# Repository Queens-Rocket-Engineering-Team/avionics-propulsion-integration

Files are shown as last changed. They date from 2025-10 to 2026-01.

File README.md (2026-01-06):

# Propulsion Integration Control Boards (Upper, Lower)
> 2025-2026 Season - Propulsion Integration Projects

-  Branch contains both board's **firmware**, **schematics**, and related **documentation and datasheets**.

### Folder Structure
- [`/Schematics`](./Schematics/) : PCB design files (KiCad V8)  
- [`/Firmware`](./Firmware/) : Arduino C/C++ code (to ESP32) for sensors, CAN/TWAI, and WiFi telemetry  
- [`/Datasheets`](./Datasheets/) : Datasheets and reference materials  
- [`.gitignore`](./.gitignore) : Build and temporary files excluded

---

**Branch created by:** Jeevan Sanchez

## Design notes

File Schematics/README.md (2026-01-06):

# LC Board Schematics

This directory contains PCB and schematic files for both LC boards (Kicad v8.0.6). 

Including:

- power managment for the ESP32 and board.
- MCU breakout circuitry, valve control, sensing circuits, communication.
- board layout and component placement.

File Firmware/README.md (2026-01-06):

# LC Board Firmware

This directory contains the ESP32 firmware for the launch control (LC) board. 

Including:

- reading sensors. 
- valve control.
- CAN protocol communication.

 Firmware is developed in Arduino C/C++ and will be flashed via USB.

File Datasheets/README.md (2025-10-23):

# LC Board Datasheets

This directory contains datasheets, reference documents, and technical notes for LC board components, including:

- ESP32 MCU
- any interfaced hardware (sensors, CAN transceiver, etc.)
- software docs (external libs, etc.)

- more documentation/notes/research can be found on the <a href="https://www.notion.so/native/qret-ohyeah/Propulsion-Integration-Projects-261401792b9b805eae9ad54960dac8c4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">Notion<a/>

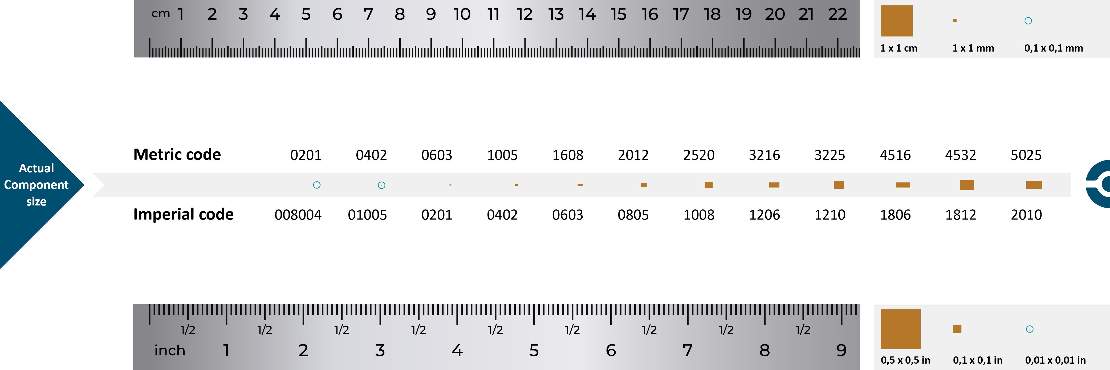
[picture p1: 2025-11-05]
Datasheets/SMD_SIZECHART.jpg

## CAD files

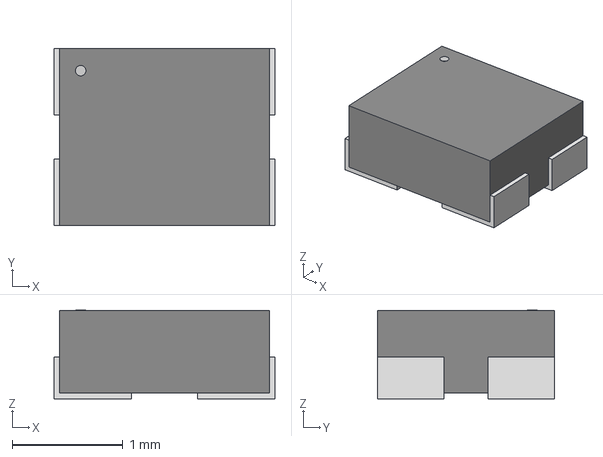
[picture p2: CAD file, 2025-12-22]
Schematics/upper_lc_board/models/SON4_SIT1602-7_SIT.step
2.00 x 1.60 x 0.803 mm

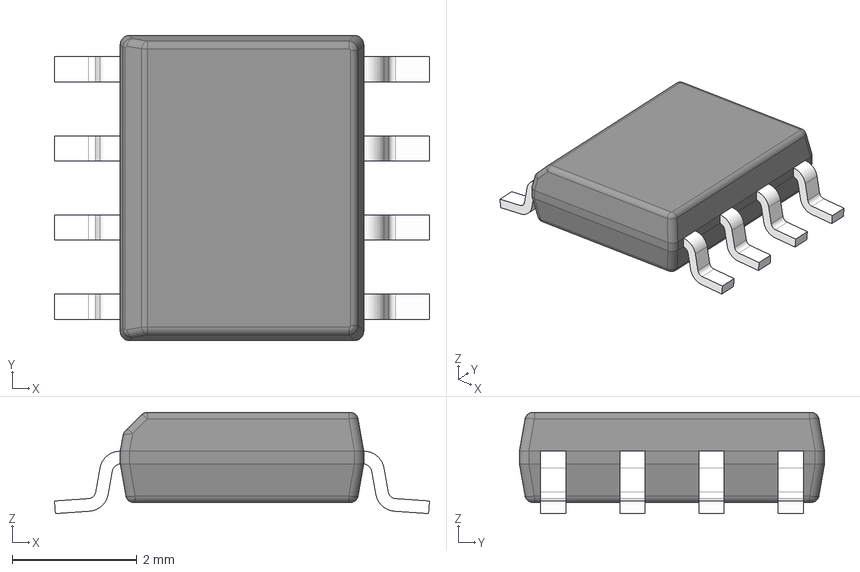
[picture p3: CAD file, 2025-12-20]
Schematics/upper_lc_board/models/D0008A.stp
6.02 x 4.90 x 1.63 mm
BODY-SO
LEAD-D0008A x 8

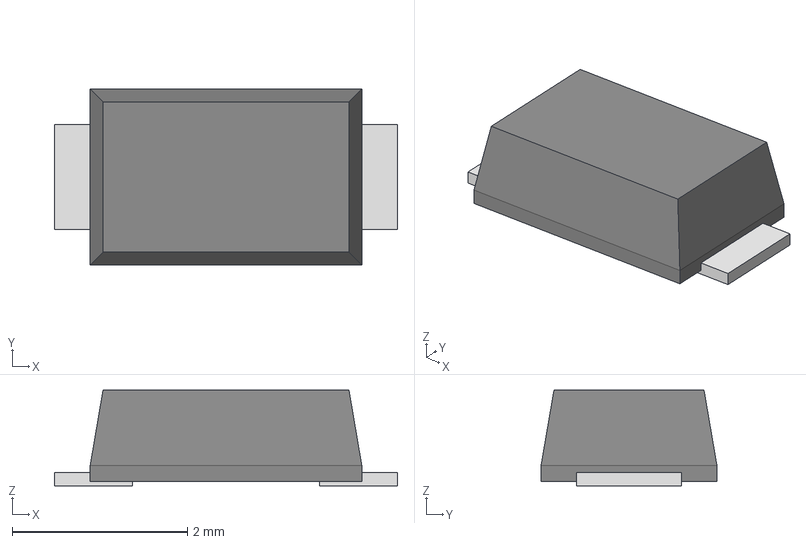
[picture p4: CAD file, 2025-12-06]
Schematics/upper_lc_board/models/SOD-123F_LTF.step
3.91 x 2.01 x 1.09 mm

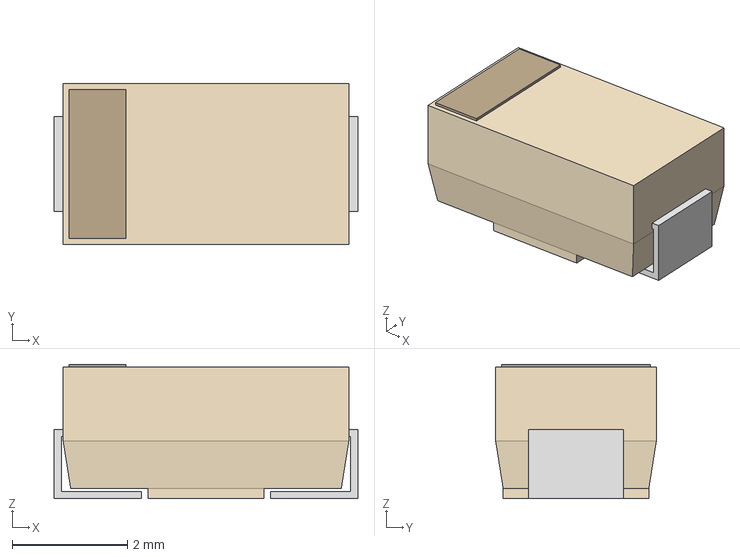
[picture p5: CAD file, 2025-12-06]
Schematics/upper_lc_board/models/SMASeries_LTF.step
5.28 x 2.79 x 2.34 mm

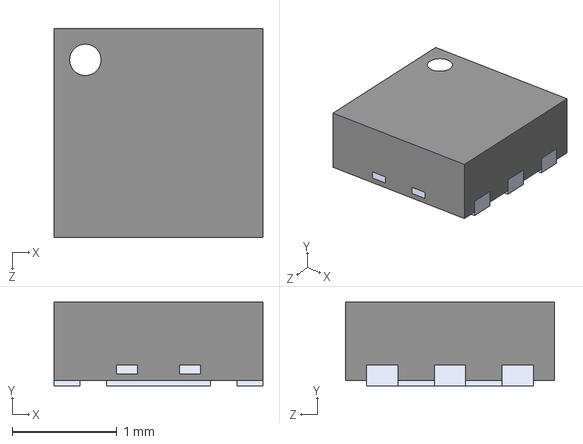
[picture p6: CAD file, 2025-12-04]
Schematics/upper_lc_board/models/TMP117MAIDRVR.step
2.00 x 0.8 x 2.00 mm

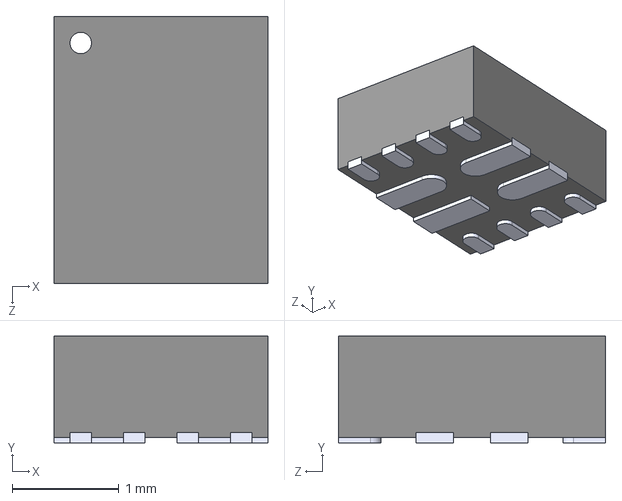
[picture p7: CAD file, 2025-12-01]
Schematics/upper_lc_board/models/TPS2121RUXR.step
2.00 x 1.00 x 2.50 mm

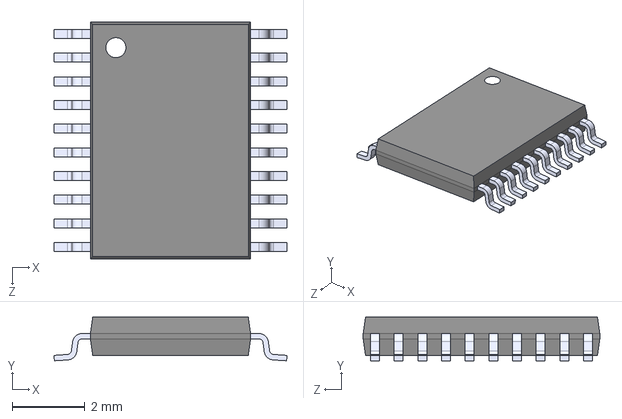
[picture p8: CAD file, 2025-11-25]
Schematics/upper_lc_board/models/ADS131M04IPWR.step
6.40 x 1.20 x 6.50 mm

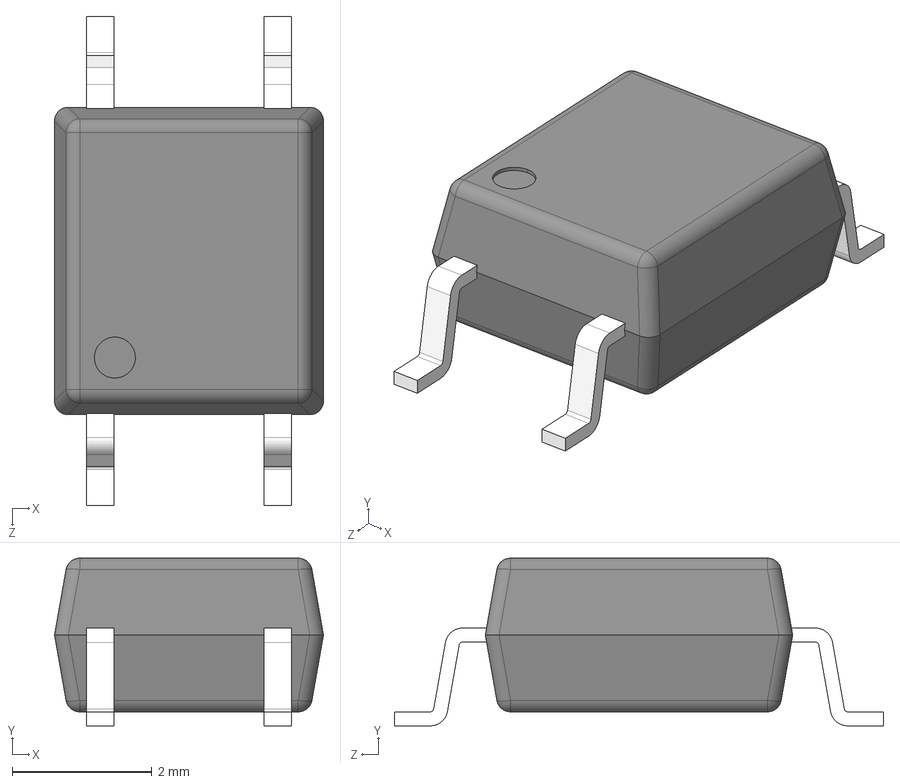
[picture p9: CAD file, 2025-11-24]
Schematics/upper_lc_board/models/VO1400AEFT1.STEP
3.85 x 2.40 x 7.00 mm

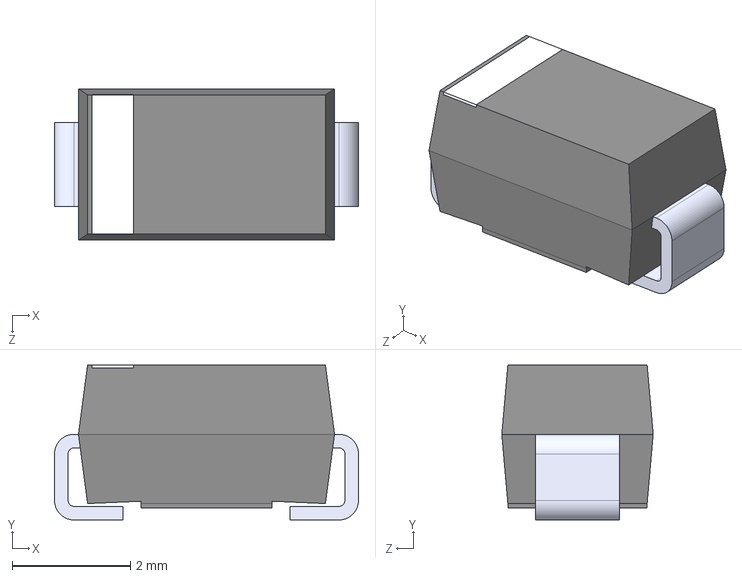
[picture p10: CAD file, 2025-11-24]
Schematics/upper_lc_board/models/US1M.step
5.14 x 2.62 x 2.56 mm

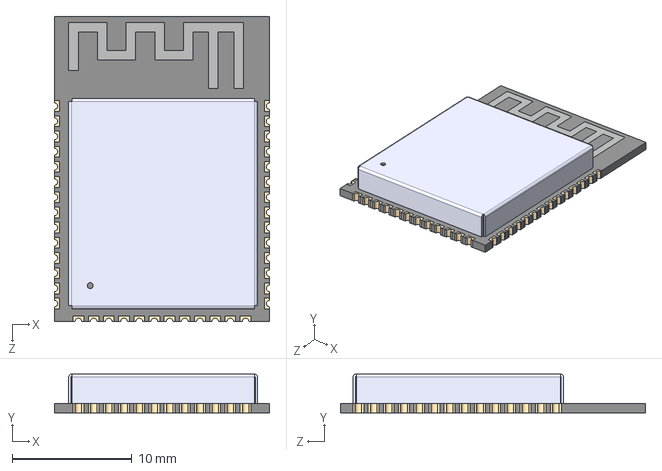
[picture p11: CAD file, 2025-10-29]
Schematics/upper_lc_board/models/ESP32-S3-WROOM-1-N16R2.step
18.0 x 3.25 x 25.5 mm

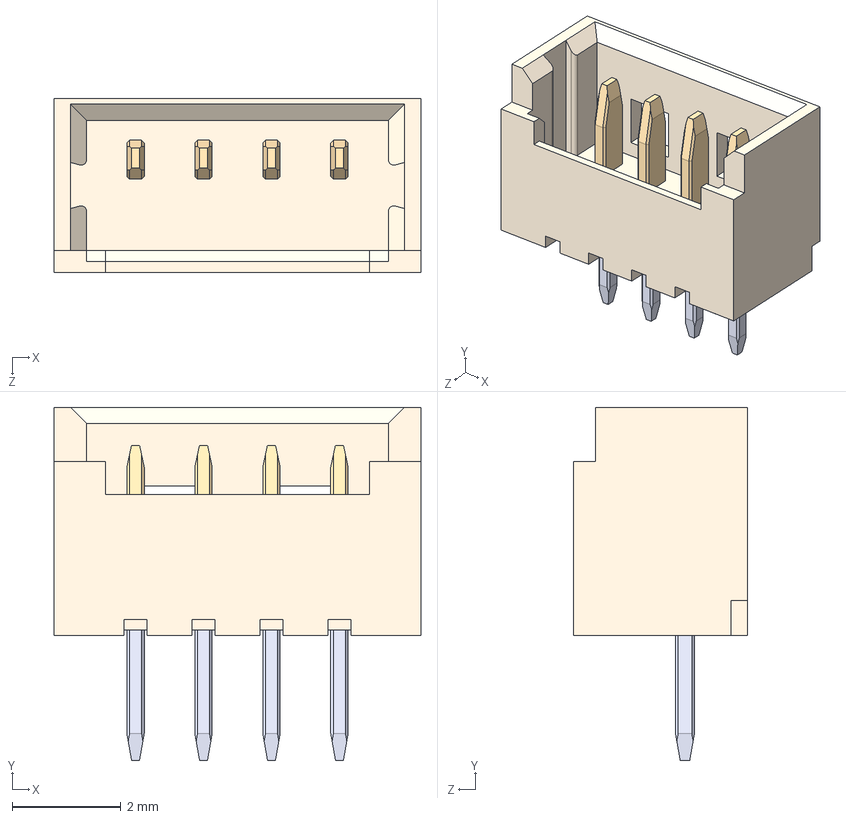
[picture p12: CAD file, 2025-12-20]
Schematics/upper_lc_board/models/53047-0460.step
6.75 x 6.50 x 3.20 mm

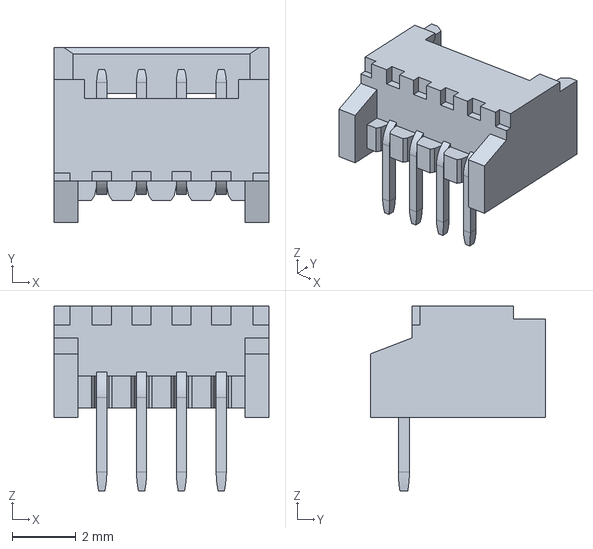
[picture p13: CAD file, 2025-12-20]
Schematics/upper_lc_board/models/530480410.step
6.75 x 5.50 x 5.80 mm

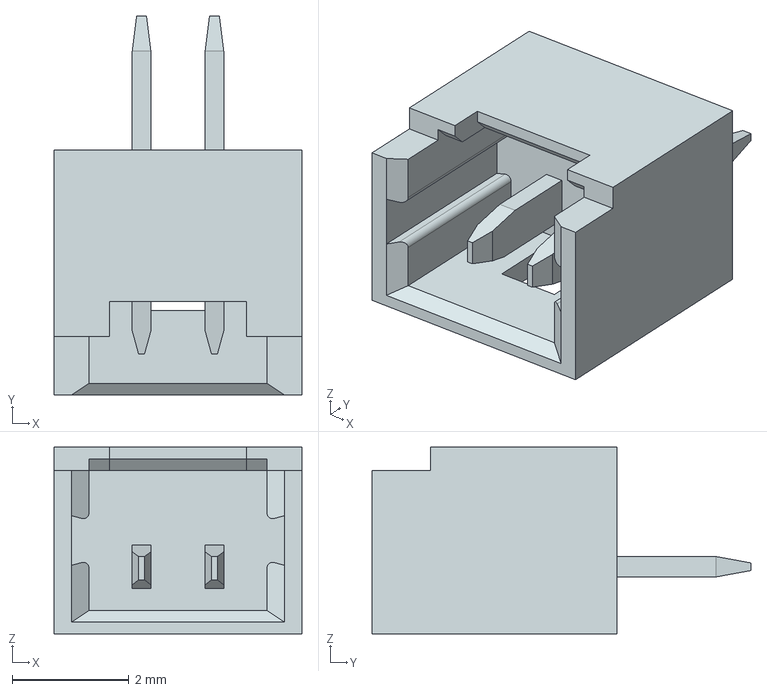
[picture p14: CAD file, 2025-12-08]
Schematics/upper_lc_board/models/530470260.stp
4.25 x 6.50 x 3.20 mm

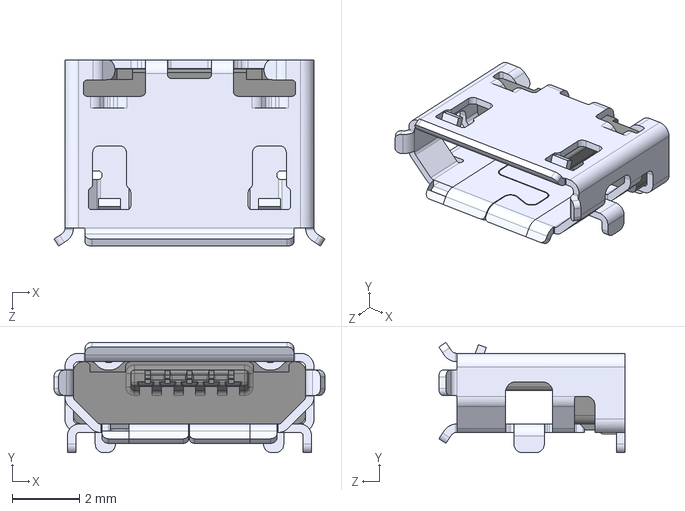
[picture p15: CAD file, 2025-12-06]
Schematics/upper_lc_board/models/10118194-0001LF-USB.step
8.05 x 3.27 x 5.53 mm

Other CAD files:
Schematics/upper_lc_board/models/282834-3.step
Schematics/upper_lc_board/models/530480210.step
Schematics/upper_lc_board/models/53048-0310.step
Schematics/upper_lc_board/models/0679L0250-05.step
Schematics/upper_lc_board/models/5019390300.stp
Schematics/upper_lc_board/models/LM66100DCKR.STEP

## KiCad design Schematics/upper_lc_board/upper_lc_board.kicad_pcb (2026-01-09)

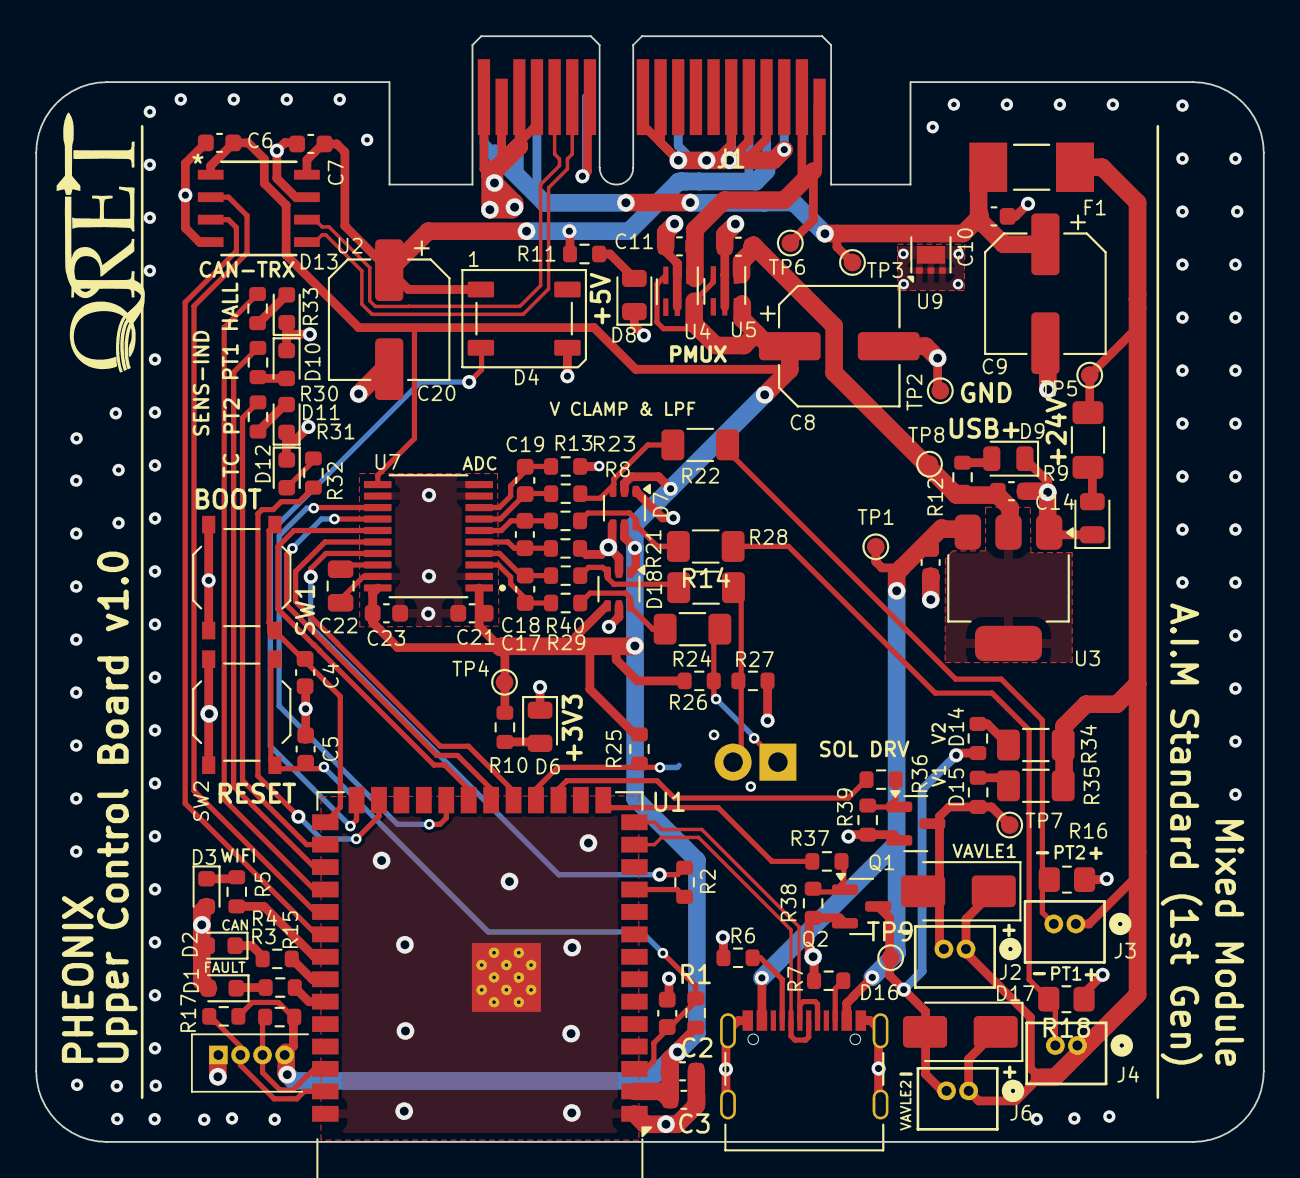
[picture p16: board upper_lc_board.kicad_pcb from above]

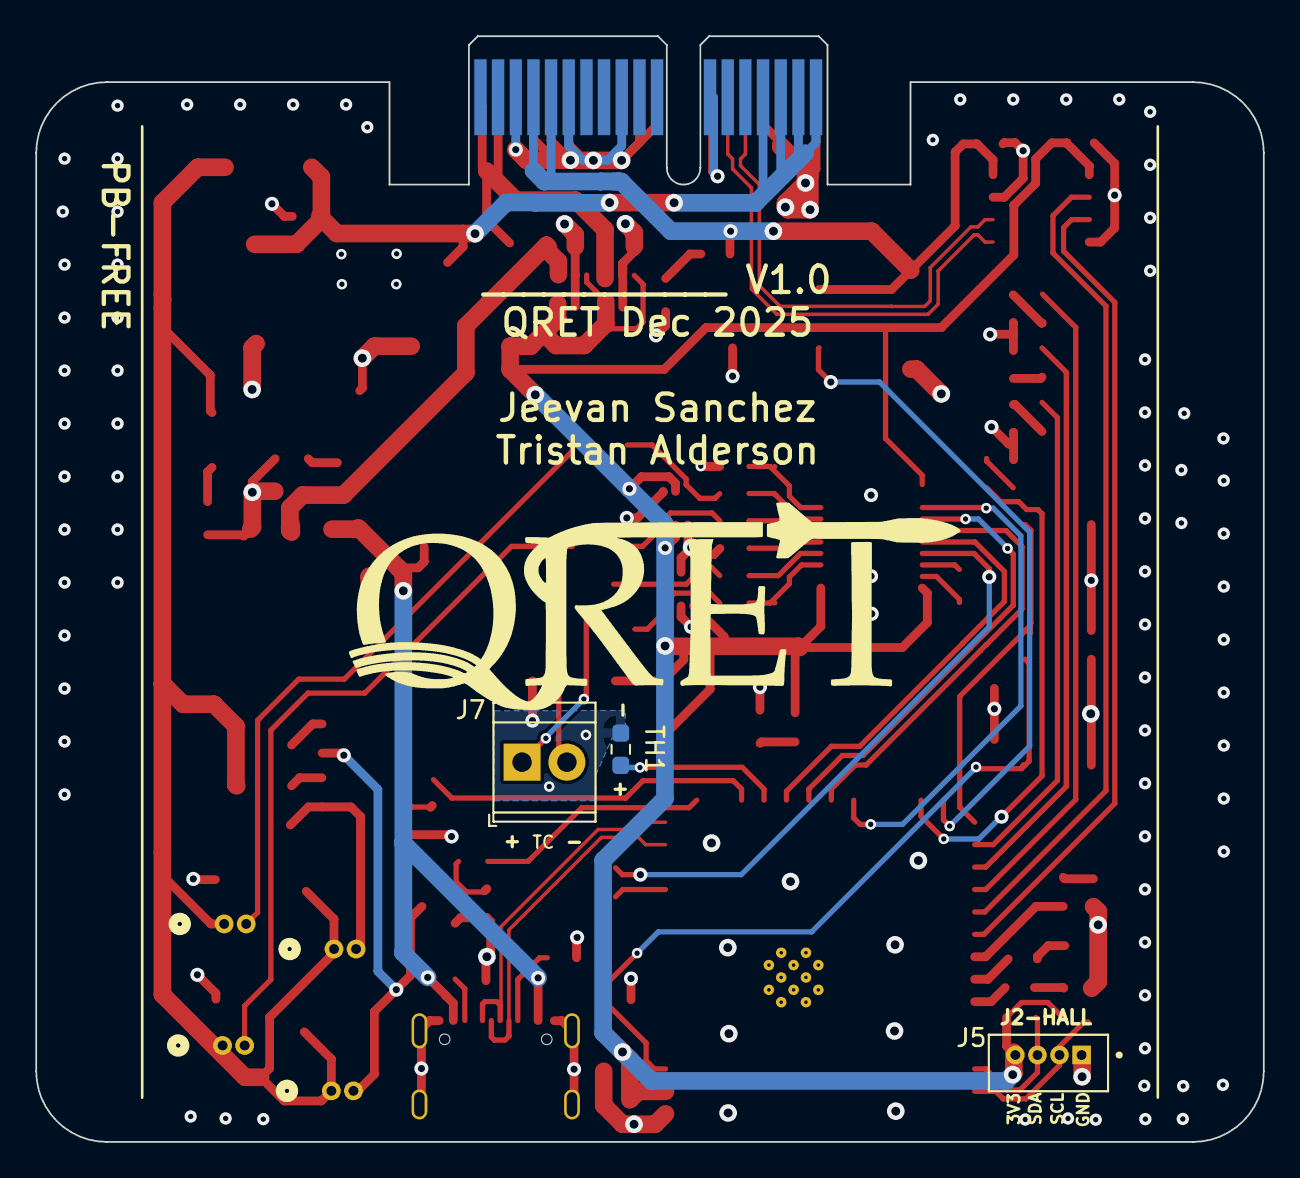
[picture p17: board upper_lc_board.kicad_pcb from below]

Board: 4 copper layers, 69.5 x 62.6 mm, 107 parts (3 on the bottom side), 69 nets.

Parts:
C1, C11, C12, C21, C23: 1uF; C_0603_1608Metric
C2, C4, C5, C6, C7, C10: 0.1uF; C_0603_1608Metric
C3, C13, C14: 10uF; C_0603_1608Metric
C8, C20: 100uF_16V; CP_Elec_6.3x5.9
C9: 100uF_35V; CP_Elec_6.3x5.9
C17, C18, C19: 10nF; C_0603_1608Metric
C22: 220 nF; C_0805_2012Metric
D1: FAULT_LED; LED_0603_1608Metric
D2: CAN_LED; LED_0603_1608Metric
D3: WIFI_LED; LED_0603_1608Metric
D4: SYS_LED_WS2812B; LED_WS2812B_PLCC4_5.0x5.0mm_P3.2mm
D5: PWR_24V_LED (GRN); LED_0805_2012Metric
D6: PWR_3V3_LED (GRN); LED_0805_2012Metric
D7, D18: BAV199DW; SOT-363_SC-70-6
D8: PWR_5V_LED (GRN); LED_0805_2012Metric
D9: USB_LED (GRN); LED_0805_2012Metric
D10, D11, D12, D13: LED; LED_0603_1608Metric
D14: SOL2_LED (YELW); R_0603_1608Metric
D15: SOL1_LED (YELW); R_0603_1608Metric
D16, D17: SS34; D_SMA
F1: Fuse; FUSC6125X279N
J1: Stack Male Edge Connector; BUS_PCIexpress_x1
J2: SOL1_CONN; CONN02_530470260_MOL
J3, J4: PT1; CONN02_530470260_MOL
J5: HALL; MOLEX_53047-0460
J6: SOL2_CONN; CONN02_530470260_MOL
J7: Screw_Terminal_01x02; TerminalBlock_TE_282834-2_1x02_P2.54mm_Horizontal
J8: USB_C_Female_USB2_Small; USB_C_DB-108PWB
Q1, Q2: AO3400A; SOT-23
R1, R25: 10k; R_0603_1608Metric
R2: 33; R_0603_1608Metric
R3, R4, R5, R10, R12, R30, R31, R32, R33: 150; R_0603_1608Metric
R6, R7: 5.1k; R_0603_1608Metric
R8, R13, R29, R36, R37, R40: 200; R_0603_1608Metric
R9, R34, R35: 4.7k; R_1206_3216Metric_Pad1.30x1.75mm_HandSolder
R11: 510; R_0603_1608Metric
R14, R22, R24, R28: 1k; R_1206_3216Metric_Pad1.30x1.75mm_HandSolder
R15, R17: 2.2k; R_0603_1608Metric
R16, R18: 165; R_0805_2012Metric_Pad1.20x1.40mm_HandSolder
R21, R23: 1.2k; R_0603_1608Metric
R26, R27: 1M; R_0603_1608Metric
R38, R39: 100k; R_0603_1608Metric
SW1: SW_ESP_BOOT_MODE; SW_Push_1P1T_XKB_TS-1187A
SW2: SW_ESP_RESET; SW_Push_1P1T_XKB_TS-1187A
TH1: Thermistor; R_0603_1608Metric_Pad0.98x0.95mm_HandSolder
TP1: 5V_USB; TestPoint_Pad_D1.0mm
TP2: GND; TestPoint_Pad_D1.0mm
TP3: 24V_BP; TestPoint_Pad_D1.0mm
TP4: 3V3; TestPoint_Pad_D1.0mm
TP5: 24V; TestPoint_Pad_D1.0mm
TP6: 3V3_BP; TestPoint_Pad_D1.0mm
TP7: VALVE1_OUT_TP; TestPoint_Pad_D1.0mm
TP8: 3V3_USB; TestPoint_Pad_D1.0mm
TP9: VALVE2_OUT_TP; TestPoint_Pad_D1.0mm
U1: ESP32-S3-WROOM-1-N16; ESP32-S3-WROOM-1
U2: ISO1044BDR; SOIC_1044BDR_TEX
U3: AMS1117-3.3; SOT-223-3_TabPin2
U4, U5: ID_LM66100DCKR; SC-70-6
U7: ADC_ADS131M04IPWR; SOP65P640X120-20N
U9: TVS3300DRV; WSON-6-1EP_2x2mm_P0.65mm_EP1x1.6mm

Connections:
5V_USB: C13.1, J8.A4 (VBUS), J8.A9 (VBUS), J8.B4 (VBUS), J8.B9 (VBUS), TP1.1, U3.3 (VI)
+3V3: C2.1, C3.1, C6.1, C8.1, C21.2, C23.2, D7.2 (K2), D7.5 (K4), D18.1 (A1), D18.4 (A3), J5.4, R1.1, R10.2, R15.2, R17.1, R25.2, R26.1, TP4.1, U1.2 (3V3), U2.1 (VCC1), U4.3 (*CE), U4.6 (VOUT), U5.3 (*CE), U5.6 (VOUT), U7.1 (AVDD), U7.11 (~SYNC/~RESET), U7.20 (DVDD)
+5V: C7.1, C20.1, D4.1 (VDD), J1.A4 (5.0V_A), J1.A5 (5.0V_A), R11.2, U2.8 (VCC2)
+24V: D16.1 (K), D17.1 (K), F1.1, J2.1, J3.1, J4.1, J6.1, R9.2, R34.2, R35.2, TP5.1
+24V_BP: C9.1, C10.1, F1.2, J1.A15 (24V_C), J1.A16 (24V_C), J1.A17 (24V_C), J1.A18 (24V_C), TP3.1, U9.4 (IN), U9.5 (IN), U9.6 (IN)
/ESP Breakout Cirucitry/ESP32_EN: C1.1, C5.2, R1.2, SW2.2, U1.3 (EN)
/ESP Breakout Cirucitry/ESP32_IO0: C4.2, SW1.2, U1.27 (IO0)
/ESP Breakout Cirucitry/GPIO_18: R2.1, U1.11 (IO18)
/ESP Breakout Cirucitry/GPIO_38: U1.31 (IO38), U2.2 (TXD)
/ESP Breakout Cirucitry/GPIO_39: U1.32 (IO39), U2.3 (RXD)
/ESP Breakout Cirucitry/GPIO_40: R5.1, U1.33 (IO40)
/ESP Breakout Cirucitry/GPIO_41: R4.1, U1.34 (IO41)
/ESP Breakout Cirucitry/GPIO_42: R3.1, U1.35 (IO42)
/ESP Breakout Cirucitry/GPIO_45: D4.2 (DOUT), U1.26 (IO45)
/ESP Breakout Cirucitry/USB_N: J8.A7 (D-), J8.B7 (D-), U1.13 (USB_D-)
/ESP Breakout Cirucitry/USB_P: J8.A6 (D+), J8.B6 (D+), U1.14 (USB_D+)
/Power Circuitry/3V3_BP: C11.2, J1.A1 (3.3V_A), J1.A2 (3.3V_A), TP6.1, U4.1 (VIN)
/Power Circuitry/3V3_USB: C12.1, C14.1, R12.1, TP8.1, U3.2 (VO), U5.1 (VIN)
/Sensor Circuitry/PT1: J4.2, R14.1, R18.2
/Sensor Circuitry/PT1_CLAMPED: C18.2, R13.1, U7.6 (AIN1P)
/Sensor Circuitry/PT2: J3.2, R16.2, R22.1
/Sensor Circuitry/PT2_CLAMPED: C19.2, R8.1, U7.7 (AIN2P)
/Sensor Circuitry/TC_N: J7.2, R27.1, R28.2
/Sensor Circuitry/TC_N_CLAMPED: C17.1, R40.2, U7.4 (AIN0N)
/Sensor Circuitry/TC_P: J7.1, R24.2, R26.2
/Sensor Circuitry/TC_P_CLAMPED: C17.2, R29.2, U7.3 (AIN0P)
ADC_CLKIN: R2.2, U7.17 (CLKIN)
ADC_DREADY: U1.22 (IO14), U7.13 (~DRDY)
ADC_MISO: U1.21 (IO13), U7.15 (DOUT)
ADC_MOSI: U1.19 (IO11), U7.16 (DIN)
ADC_SCLK: U1.20 (IO12), U7.14 (SCLK)
CAN_+: J1.B14 (CAN_H), U2.6 (CANH)
CAN_-: J1.B13 (CAN_L), U2.5 (CANL)
GND: C1.2, C2.2, C3.2, C4.1, C5.1, C6.2, C7.2, C8.2, C9.2, C10.2, C11.1, C12.2, C13.2, C14.2, C20.2, C21.1, C22.2, C23.1, D1.2 (A), D2.2 (A), D3.2 (A), D4.3 (VSS), D5.1 (K), D6.1 (K), D7.1 (A1), D7.4 (A3), D8.1 (K), D9.1 (K), D10.1 (K), D11.1 (K), D12.1 (K), D13.1 (K), D18.2 (K2), D18.5 (K4), J1.A3 (GND_A), J1.A6 (GND_A), J1.A9 (GND_B), J1.A12 (GND_B), J1.B4 (GND_A), J1.B5 (GND_A), J1.B6 (GND_A), J1.B10 (GND_B), J1.B11 (GND_B), J1.B12 (GND_B), J1.B15 (GND_C), J1.B16 (GND_C), J1.B17 (GND_C), J1.B18 (GND_C), J5.1, J8.A1 (GND), J8.A12 (GND), J8.B1 (GND), J8.B12 (GND), J8.S1 (SHIELD), Q1.2 (S), Q2.2 (S), R6.2, R7.2, R16.1, R18.1, R21.1, R23.1, R27.2, R38.1, R39.1, SW1.1, SW2.1, TH1.2, TP2.1, U1.1 (GND), U1.40 (GND), U1.41 (GND), U2.4 (GND1), U2.7 (GND2), U3.1 (GND), U4.2 (GND), U4.5 (ST), U5.2 (GND), U5.5 (ST), U7.2 (AGND), U7.9 (AIN3N), U7.10 (AIN3P), U7.12 (~CS), U7.19 (DGND), U9.1 (GND), U9.2 (GND), U9.3 (GND), U9.7 (GND)
HALL_LED: R33.1, U1.30 (IO37)
HALL_SCL: J5.2, R17.2, U1.39 (IO1)
HALL_SDA: J5.3, R15.1, U1.38 (IO2)
unnamed: D1.1 (K), R3.2
unnamed: D2.1 (K), R4.2
unnamed: D3.1 (K), R5.2
unnamed: D5.2 (A), R9.1
unnamed: D6.2 (A), R10.1
unnamed: D7.6 (K3A4), R13.2, R14.2
unnamed: D7.3 (K1A2), R8.2, R22.2
unnamed: D8.2 (A), R11.1
unnamed: D9.2 (A), R12.2
unnamed: D10.2 (A), R30.2
unnamed: D11.2 (A), R31.2
unnamed: D12.2 (A), R32.2
unnamed: D13.2 (A), R33.2
unnamed: D14.2 (A), R34.1
unnamed: D15.2 (A), R35.1
unnamed: D18.6 (K3A4), R24.1, R29.1
unnamed: D18.3 (K1A2), R28.1, R40.1
unnamed: J8.A5 (CC1), R6.1
unnamed: J8.B5 (CC2), R7.1
unnamed: Q1.1 (G), R36.1, R39.2
unnamed: Q2.1 (G), R37.1, R38.2
unnamed: C18.1, R21.2, U7.5 (AIN1N)
unnamed: C19.1, R23.2, U7.8 (AIN2N)
unnamed: C22.1, U7.18 (CAP)
PT1_LED: R30.1, U1.29 (IO36)
PT2_LED: R31.1, U1.28 (IO35)
SOL1_RET: D15.1 (K), D16.2 (A), J2.2, Q1.3 (D), TP7.1
SOL2_RET: D14.1 (K), D17.2 (A), J6.2, Q2.3 (D), TP9.1
TC_LED: R32.1, U1.25 (IO48)
TEMP_SENSE: R25.1, TH1.1, U1.18 (IO10)
VALVE1_CTRL: R36.2, U1.17 (IO9)
VALVE2_CTRL: R37.2, U1.15 (IO3)

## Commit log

2025-03-18 Fixed power LED voltage sources
    5V and 12V LEDs were connected to 3.3V. Thanks Teighin :)
    [GS_Mainboard.kicad_sch]
2025-03-20 Changed to higher-performance sensors
    Changed main sensors to pin-compatible versions with higher performance:
    - Changed MS5607 to MS5611
    - Changed QMA6100P to KX134ACR
    No PCB changed are required.
    [Altimeter_Module.kicad_sch]
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2025-10-10 init base repo for LC board
    [10018784-10210TLF.step, 10118194-0001LF-USB.step, 8890445_SWD_PINS.stp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]
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2025-10-29 add more datasheets, PCB files (main, breakout)
    [ESP32-S3-WROOM-1-N16R2.step, ESP32_breakout.kicad_pcb, ESP32_breakout.kicad_sch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]
2025-11-05 breakout circuitry complete, added datasheets
    [ESP_breakout.kicad_sch, SN65HVD230DR.step]
2025-11-07 update breakout circuitry (check documentation on notion), power module.
    [ESP_breakout.kicad_sch, LM66100DCKR.step, power_module.kicad_pcb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]
2025-11-13 add power module with ORing circuit, add datasheets on each symbol.
    [ESP_breakout.kicad_sch, power_module.kicad_sch, upper_lc_board.kicad_sch]
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2025-11-19 update power circuitry with new backplane symbol
    [ESP_breakout.kicad_sch, power_module.kicad_sch, upper_lc_board.kicad_sch]
2025-11-21 finish sensor circuitry & add sensor documentation to notion.
    [ESP_breakout.kicad_sch, PBS0032A.stl, sensor_module.kicad_sch]
2025-11-21 restructure file structure, start solenoid driver circuitry
    [ESP32-S3-WROOM-1-N16R2.step, ESP_breakout.kicad_pcb, ESP_breakout_module.kicad_sch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]
2025-11-22 start solenoid driver circuitry
    [ESP_breakout_module.kicad_sch, solenoid_module.kicad_sch]
2025-11-22 add solenoid driver circuitry
    [ESP_breakout_module.kicad_sch, power_module.kicad_sch, sensor_module.kicad_sch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]
2025-11-22 SSR replacement for solenoid driver
    [ESP_breakout_module.kicad_sch, power_module.kicad_sch, sensor_module.kicad_sch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]
2025-11-23 add hiearchical sheets in main board file
    [ESP_breakout_module.kicad_sch, power_module.kicad_sch, sensor_module.kicad_sch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]
2025-11-24 global symbols/component annotations fix
    [ESP_breakout_module.kicad_sch, power_module.kicad_sch, sensor_module.kicad_sch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]
2025-11-24 start PCB file, start assigning footprints, omit fuse, JST conns for now, still assigning resistors and some diodes
    [ABLS3-16.384MHZ-D4Y-T.step, Blade Fuse.stp, ESP32-S3-WROOM-1-N8R2--3DModel-STEP-56544.STEP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]
2025-11-24 start layout, finish assigning footprints. TODO -> verify ESP32 pinout, continue layout
    [ABM3-8.000MHZ-D2Y-T--3DModel-STEP-400430.STEP, US1M.step, power_module.kicad_sch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]
2025-11-24 layout update; still need to add small components (caps, resistors), and add silkscreen
    [BSS138.step, ESP_breakout_module.kicad_sch, IRFZ44NSPBF.step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]
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2025-11-25 update board, add new fuse
    [0679L0250-05.step, power_module.kicad_sch, sensor_module.kicad_sch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]
2025-11-25 add new adc to schematic
    [ADS131M04IPWR.step, SIT8208AI-G3-33E-65.000000T.step, sensor_module.kicad_sch]
2025-11-25 update board with new ADC & crystal
    [upper_lc_board.kicad_pcb]
2025-11-25 start revising main layout for accessibility
    [upper_lc_board.kicad_pcb]
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2025-11-27 start redesigning ADC circuitry, organize schematic files. adding OPAMPS for buffered voltage divider on HALL & on PTs. layout to be adjusted after.
    [ESP_breakout_module.kicad_sch, power_module.kicad_sch, sensor_module.kicad_sch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]
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2025-12-01 update power circuitry (replaced OR-ing setup with a single power mux IC)
    [Blade Fuse.stp, LM66100DCKR.step, TPS2121RUXR.step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]
2025-12-01 solenoid schematic review, reveiewing sensors and ESP-breakout next, then finalizing layout
    [power_module.kicad_sch, solenoid_module.kicad_sch]
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2025-12-06 update schematic & board with smaller diode footprints
    [SDM4A40EP3-7B.stp, SMASeries_LTF.step, SMBJ28A.step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]
2025-12-06 fix footprint designators
    [ESP_breakout_module.kicad_sch, solenoid_module.kicad_sch, upper_lc_board.kicad_pcb]
2025-12-06 layout work, implement ADC low pass filter layout next
    [upper_lc_board.kicad_pcb]
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2025-12-06 revise & organize some circuitry, next: replace MUX with ideal diodes, finish layout, rename GPIO labels for clarity
    [10118194-0001LF-USB.step, ESP_breakout_module.kicad_sch, power_module.kicad_sch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]
2025-12-07 more layout work, add FAULT LED
    next: revert to ideal diode circuitry instead of MUX IC.
    [ESP_breakout_module.kicad_sch, sensor_module.kicad_sch, upper_lc_board.kicad_pcb]
2025-12-08 add vertical connectors, revert MUX circuitry to ORing setup w ideal diodes
    [530470260.stp, LM66100DCKR.STEP, power_module.kicad_sch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]
2025-12-08 finish adding components to layout, revise layout next.
    [ESP_breakout_module.kicad_sch, power_module.kicad_sch, upper_lc_board.kicad_pcb]
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2025-12-11 fix button footprint issue
    [ESP_breakout_module.kicad_sch, upper_lc_board.kicad_pcb]
2025-12-12 fix shunt resistor, add test point to layout
    - sync issue with backplane connector footprint
    [ESP_breakout_module.kicad_sch, power_module.kicad_sch, sensor_module.kicad_sch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]
2025-12-14 start routing
    - routing done for solenoids, power, and some other sub-circuits.
    [power_module.kicad_sch, upper_lc_board.kicad_pcb]
2025-12-15 route ADC circuitry, some more sensor & misc. routing
    -> low pass filter routing was a pain
    [upper_lc_board.kicad_pcb]
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2025-12-19 Init commit of cleaned up hybrid power module
    [Hybrid_Power_Module.kicad_pcb, Hybrid_Power_Module.kicad_sch, max1773r_charger.kicad_sch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]
2025-12-19 Revert "Init commit of cleaned up hybrid power module"
    This reverts commit 1ed412c4767fa7241b6af34ec0461c7642127650.
    [Hybrid_Power_Module.kicad_pcb, Hybrid_Power_Module.kicad_sch, max1773r_charger.kicad_sch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]
2025-12-19 fixed/updated CAN transceiver
    [ESP_breakout_module.kicad_sch, ISO1042BDWVR.step]
2025-12-20 add new CAN, 4-pin conn for hall sensor, general routing work.
    #TODO - clear design rules check
    [53047-0460.step, 530480410.step, D0008A.stp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]
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2025-12-22 Updated all gpio for better routing, > - removed diode array, and 5v sensing > - added dedicated clk generator for adc
    [ESP_breakout_module.kicad_sch, SON4_SIT1602-7_SIT.step, power_module.kicad_sch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]
2025-12-23 added serial comm support and automatic flashing via uart bridge
    [ESP_breakout_module.kicad_sch, power_module.kicad_sch]
2025-12-24 fixed pin naming convention and updated gpios for better routing
    [ESP_breakout_module.kicad_sch, sensor_module.kicad_sch, solenoid_module.kicad_sch]
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2025-12-24 small update to adc ground plane and touch point placement
    [upper_lc_board.kicad_pcb]
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2025-12-24 switching to primarily 0603 footprints and started adding LSCS numbers
    [ESP_breakout_module.kicad_sch, power_module.kicad_sch, sensor_module.kicad_sch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]
2025-12-26 added most part number (LCSC, Digikey), verified current limiting resitors
    [ESP_breakout_module.kicad_sch, power_module.kicad_sch, sensor_module.kicad_sch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]
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2025-12-28 fix failed merge, fix part number issues
    [ESP_breakout_module.kicad_sch, power_module.kicad_sch, sensor_module.kicad_sch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]
2025-12-28 cleanup thermocouple routing, add ground pour for thermistor
    [sensor_module.kicad_sch, upper_lc_board.kicad_pcb]
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2025-12-29 fixed incorrect footprints and part numbers
    [power_module.kicad_sch, sensor_module.kicad_sch, upper_lc_board.kicad_pcb]
2025-12-29 updated opamp, 24v tvs diode, and excluded usbc antenna overlap error
    [power_module.kicad_sch, sensor_module.kicad_sch, upper_lc_board.kicad_pcb]
2025-12-29 fixed valve FB diode footprints, fixed major silkscreen warnings
    [ESP_breakout_module.kicad_sch, power_module.kicad_sch, sensor_module.kicad_sch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]
2026-01-01 updates after review using screw terminal for TC removed opamps for clamping diodes fixed solenoid FB diodes manual solder large SMDs on edges
    [ESP_breakout_module.kicad_sch, power_module.kicad_sch, sensor_module.kicad_sch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]
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2026-01-06 add hierarchy sheet blocks for valve, TC & PT circuitry.
    confirmed that nets are consistent with layout, no problems.
    [ESP_breakout_module.kicad_sch, PT_module.kicad_sch, TC_module.kicad_sch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]
2026-01-06 fix merge issue
    [sensor_module.kicad_sch, solenoid_module.kicad_sch]
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2026-01-09 init commit for allowing shared schematics accross kicad projects
    [PT_module.kicad_sch, TC_module.kicad_sch, VALVE_control.kicad_sch]
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2026-01-09 fixed TC, PT, Valve schematic references and confirmed by updating PCB
    [sensor_module.kicad_sch, solenoid_module.kicad_sch, upper_lc_board.kicad_pcb]
